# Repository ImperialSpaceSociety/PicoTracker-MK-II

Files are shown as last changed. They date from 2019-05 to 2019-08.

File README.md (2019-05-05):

# Pico Balloon Tracker Version 2.0

## Objectives
This Pico balloon tracker is the second version to be designed by Imperial College Space Society. It is intended to offer an easy to build and low cost entry for people who want to launch small Helium filled balloons with a small tracking payload. While the previous version used already built commercial modules for the radio, GPS and power supply, this version is built from basic components.
Ideally, it should be able to fly around the world on board a small balloon.

## License

Hardware is Licensed under CERN OHL v.1.2 or later https://www.ohwr.org/documents/294 No warranty is provided for this documentation implied or otherwise.

Software is licensed under MIT License.

MIT License

Copyright (c) 2018 Imperial College Space Society

Derived Software  Copyright (c) 2014  Richard Meadows <richardeoin>

Permission is hereby granted, free of charge, to any person obtaining a copy of this software and associated documentation files (the "Software"), to deal in the Software without restriction, including without limitation the rights to use, copy, modify, merge, publish, distribute, sublicense, and/or sell copies of the Software, and to permit persons to whom the Software is furnished to do so, subject to the following conditions:

The above copyright notice and this permission notice shall be included in all copies or substantial portions of the Software.

THE SOFTWARE IS PROVIDED "AS IS", WITHOUT WARRANTY OF ANY KIND, EXPRESS OR IMPLIED, INCLUDING BUT NOT LIMITED TO THE WARRANTIES OF MERCHANTABILITY, FITNESS FOR A PARTICULAR PURPOSE AND NONINFRINGEMENT. IN NO EVENT SHALL THE AUTHORS OR COPYRIGHT HOLDERS BE LIABLE FOR ANY CLAIM, DAMAGES OR OTHER LIABILITY, WHETHER IN AN ACTION OF CONTRACT, TORT OR OTHERWISE, ARISING FROM, OUT OF OR IN CONNECTION WITH THE SOFTWARE OR THE USE OR OTHER DEALINGS IN THE SOFTWARE.

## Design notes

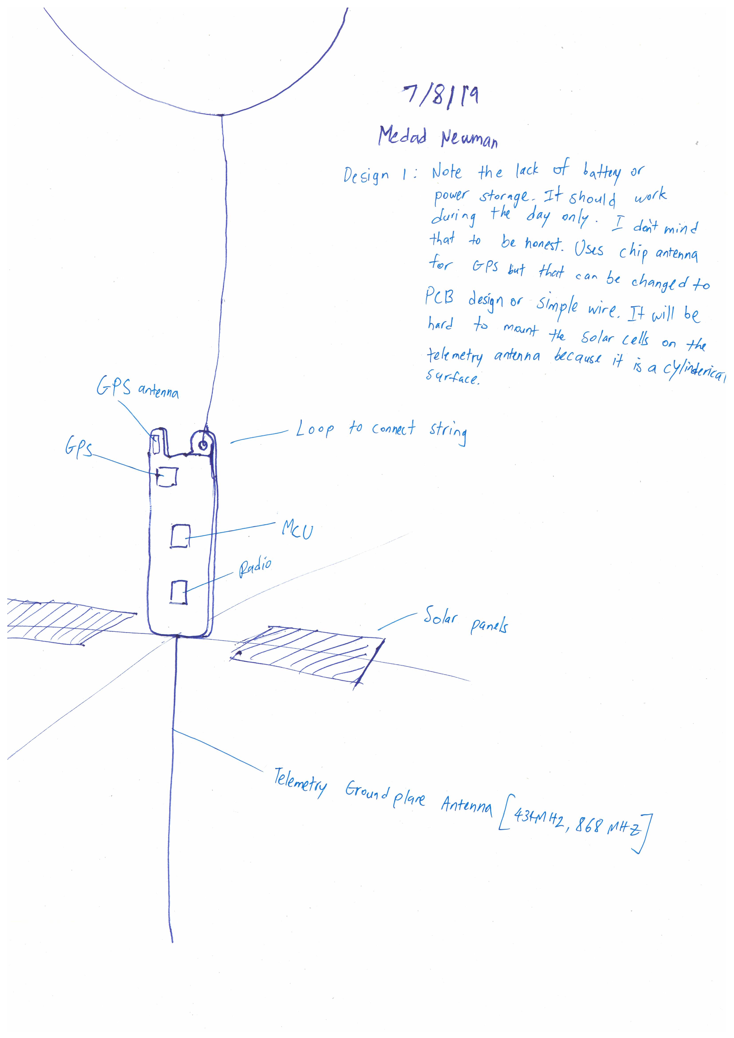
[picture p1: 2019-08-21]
prototype/hardware/Plans/Design 1.jpg

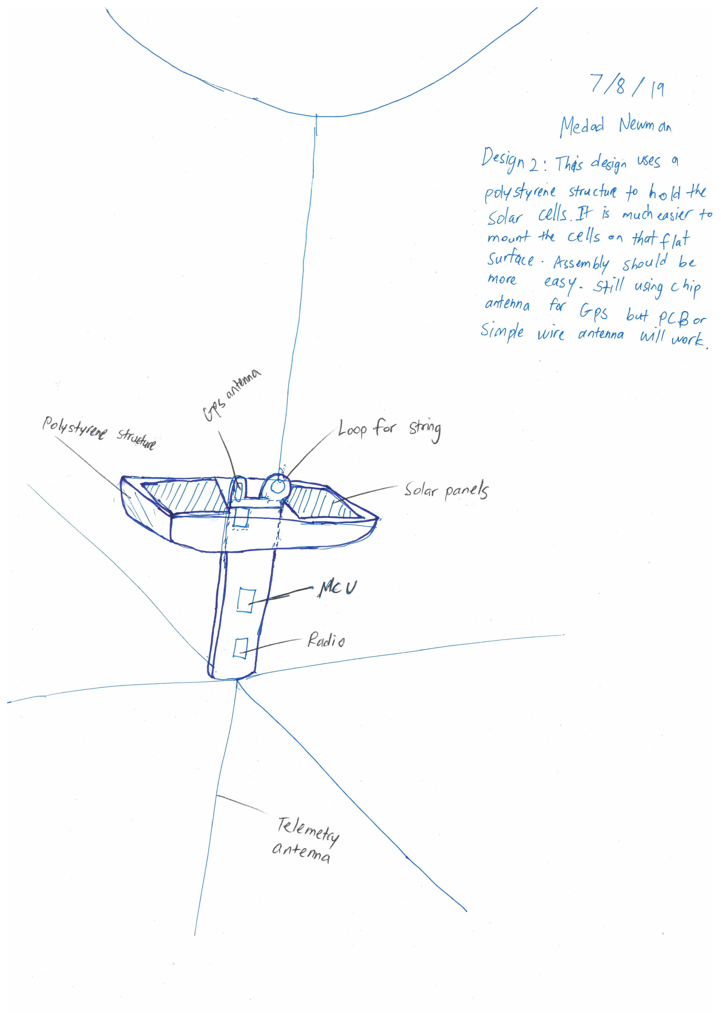
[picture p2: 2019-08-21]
prototype/hardware/Plans/Design 2.jpg

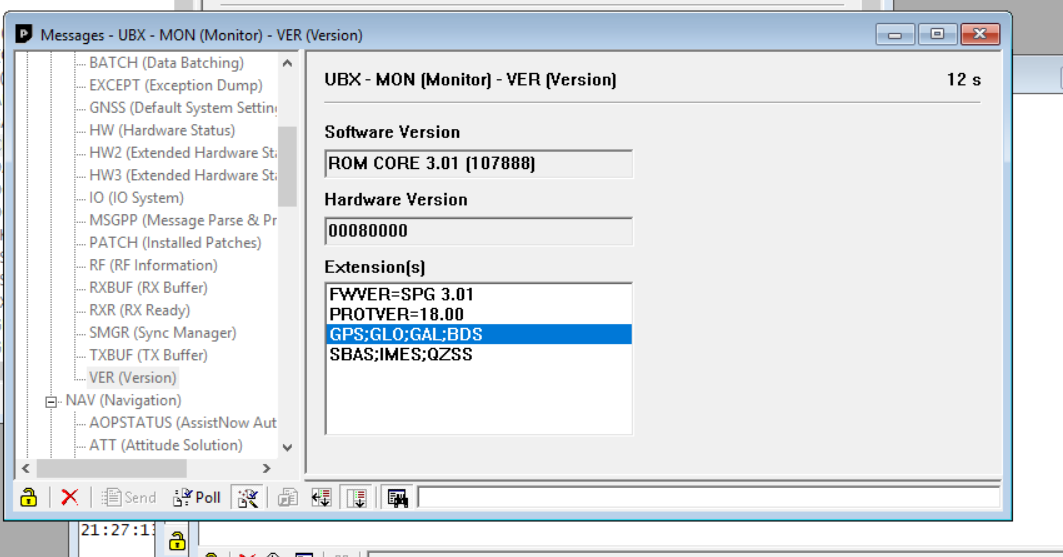
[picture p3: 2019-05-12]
prototype/hardware/GPS information/version information.PNG

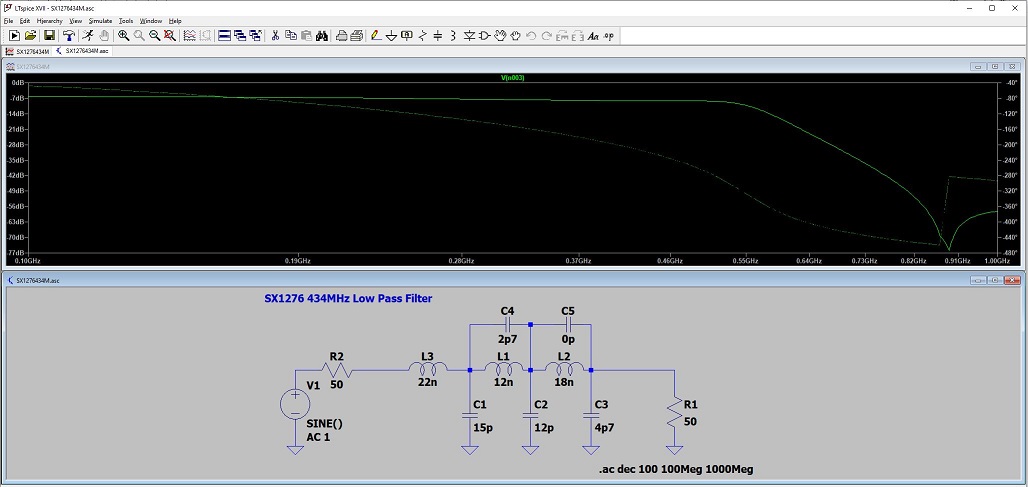
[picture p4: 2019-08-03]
Spice/SX1276434MHz.JPG

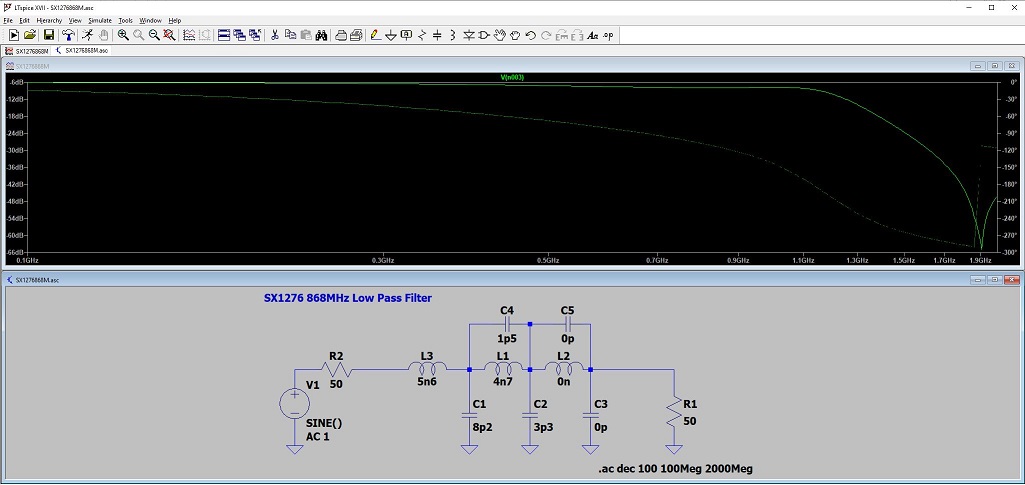
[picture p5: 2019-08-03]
Spice/SX1276868MHz.JPG

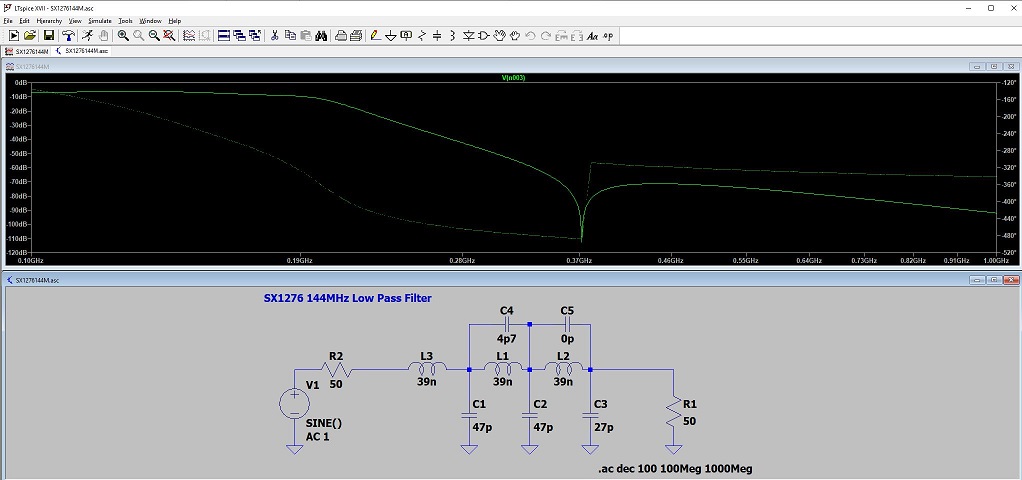
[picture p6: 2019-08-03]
Spice/SX1276144MHz.JPG

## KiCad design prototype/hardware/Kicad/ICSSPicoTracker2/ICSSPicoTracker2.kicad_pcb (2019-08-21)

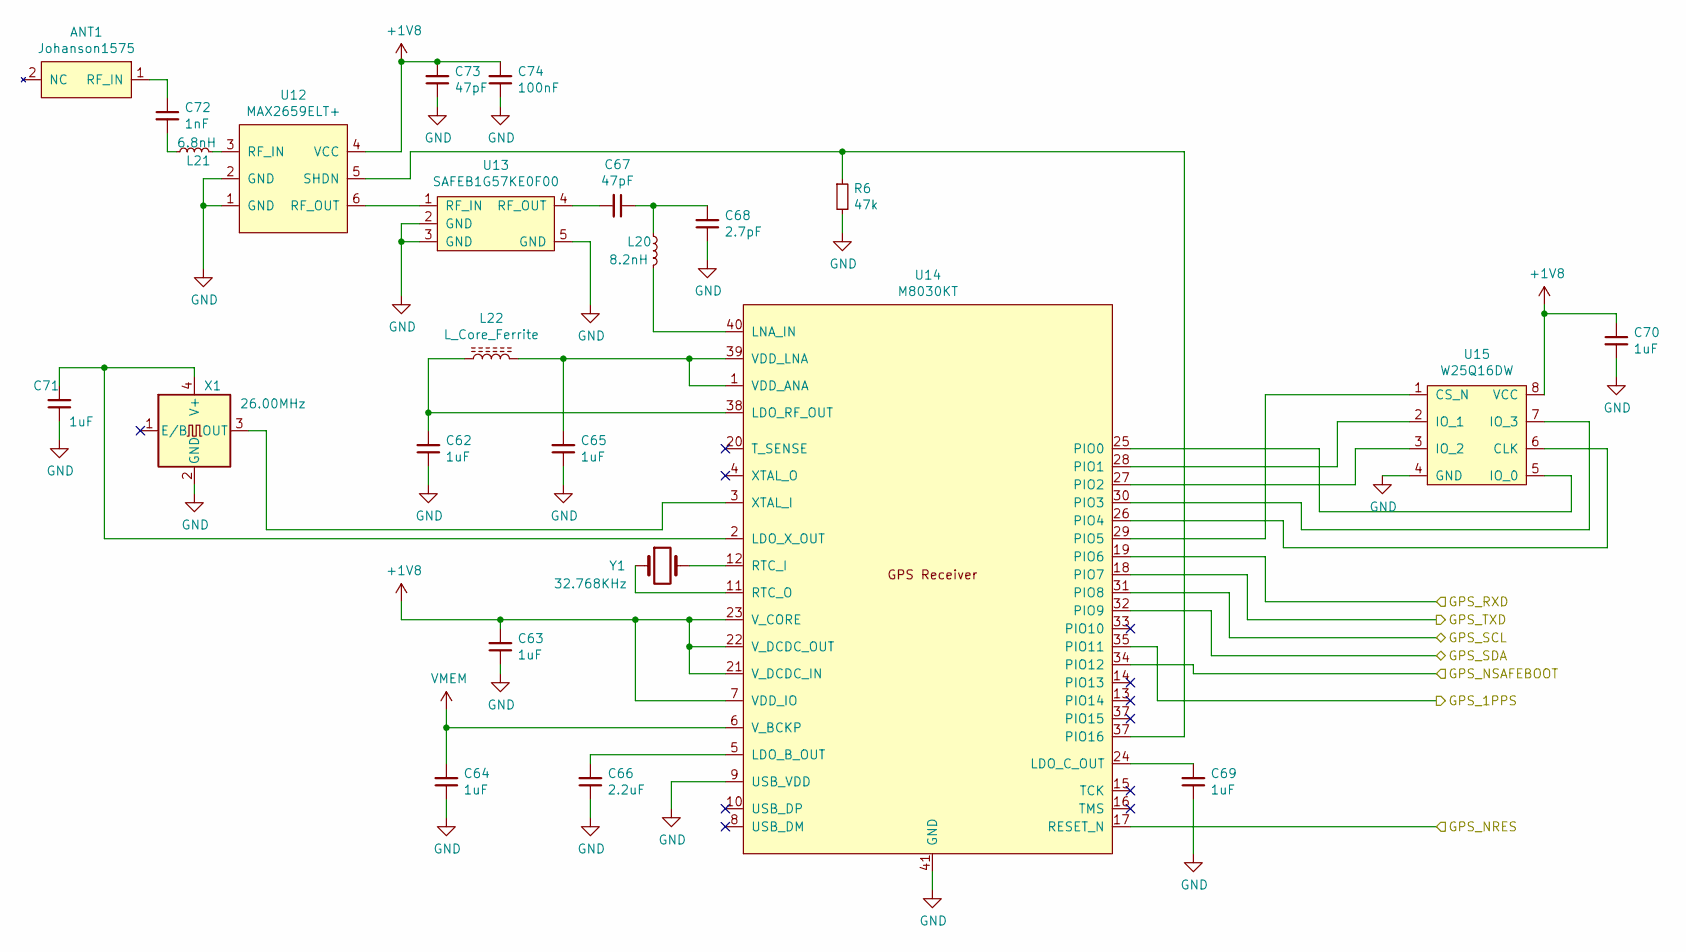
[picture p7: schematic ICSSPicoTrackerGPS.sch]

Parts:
ANT1: Johanson1575
C62, C63, C64, C65, C69, C70, C71: 1uF; C_0603_1608Metric
C66: 2.2uF; C_0603_1608Metric
C67, C73: 47pF; C_0402_1005Metric
C68: 2.7pF; C_0402_1005Metric
C72: 1nF; C_0402_1005Metric
C74: 100nF; C_0603_1608Metric
L20: 8.2nH; L_0402_1005Metric
L21: 6.8nH; L_0402_1005Metric
L22: L_Core_Ferrite; L_0603_1608Metric
R6: 47k; R_0603_1608Metric
U12: MAX2659ELT+; uDFN-6_1.0x1.5mm_P0.5mm
U13: SAFEB1G57KE0F00; Murata SAFE
U14: M8030KT; QFN-40-1EP_5x5mm_P0.4mm_EP3.6x3.6mm_ThermalVias
U15: W25Q16DW; WSON-8-1EP_6x5mm_P1.27mm_EP3.4x4.3mm
X1: 26.00MHz; Oscillator_SMD_IQD_IQXO70-4Pin_7.5x5.0mm
Y1: 32.768KHz; Crystal_SMD_2012-2Pin_2.0x1.2mm

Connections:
+1V8: C63.2, C70.1, C73.2, C74.2, U12.4 (VCC), U14.7 (VDD_IO), U14.21 (V_DCDC_IN), U14.22 (V_DCDC_OUT), U14.23 (V_CORE), U15.8 (VCC); also elsewhere on the board
/GPS/GPS_1PPS: U14.35 (PIO11); also elsewhere on the board
/GPS/GPS_NRES: U14.17 (RESET_N); also elsewhere on the board
/GPS/GPS_NSAFEBOOT: U14.34 (PIO12); also elsewhere on the board
/GPS/GPS_RXD: U14.19 (PIO6); also elsewhere on the board
/GPS/GPS_SCL: U14.31 (PIO8); also elsewhere on the board
/GPS/GPS_SDA: U14.32 (PIO9); also elsewhere on the board
/GPS/GPS_TXD: U14.18 (PIO7); also elsewhere on the board
GND: C62.1, C63.1, C64.1, C65.1, C66.1, C68.1, C69.1, C70.2, C71.1, C73.1, C74.1, R6.2, U12.1 (GND), U12.2 (GND), U13.2 (GND), U13.3 (GND), U13.5 (GND), U14.9 (USB_VDD), U14.41 (GND), U15.4 (GND), X1.2 (GND); also elsewhere on the board
unnamed: ANT1.1 (RF_IN), C72.1
unnamed: C62.2, L22.1, U14.38 (LDO_RF_OUT)
unnamed: C65.2, L22.2, U14.1 (VDD_ANA), U14.39 (VDD_LNA)
unnamed: C66.2, U14.5 (LDO_B_OUT)
unnamed: C67.1, C68.2, L20.1
unnamed: C67.2, U13.4 (RF_OUT)
unnamed: C69.2, U14.24 (LDO_C_OUT)
unnamed: C71.2, U14.2 (LDO_X_OUT), X1.4 (V+)
unnamed: C72.2, L21.2
unnamed: L20.2, U14.40 (LNA_IN)
unnamed: L21.1, U12.3 (RF_IN)
unnamed: U12.6 (RF_OUT), U13.1 (RF_IN)
unnamed: U14.3 (XTAL_I), X1.3 (OUT)
unnamed: U14.11 (RTC_O), Y1.1
unnamed: U14.12 (RTC_I), Y1.2
unnamed: U14.25 (PIO0), U15.5 (IO_0)
unnamed: U14.26 (PIO4), U15.6 (CLK)
unnamed: U14.27 (PIO2), U15.3 (IO_2)
unnamed: U14.28 (PIO1), U15.2 (IO_1)
unnamed: U14.29 (PIO5), U15.1 (CS_N)
unnamed: U14.30 (PIO3), U15.7 (IO_3)
VMEM: C64.2, U14.6 (V_BCKP); also elsewhere on the board

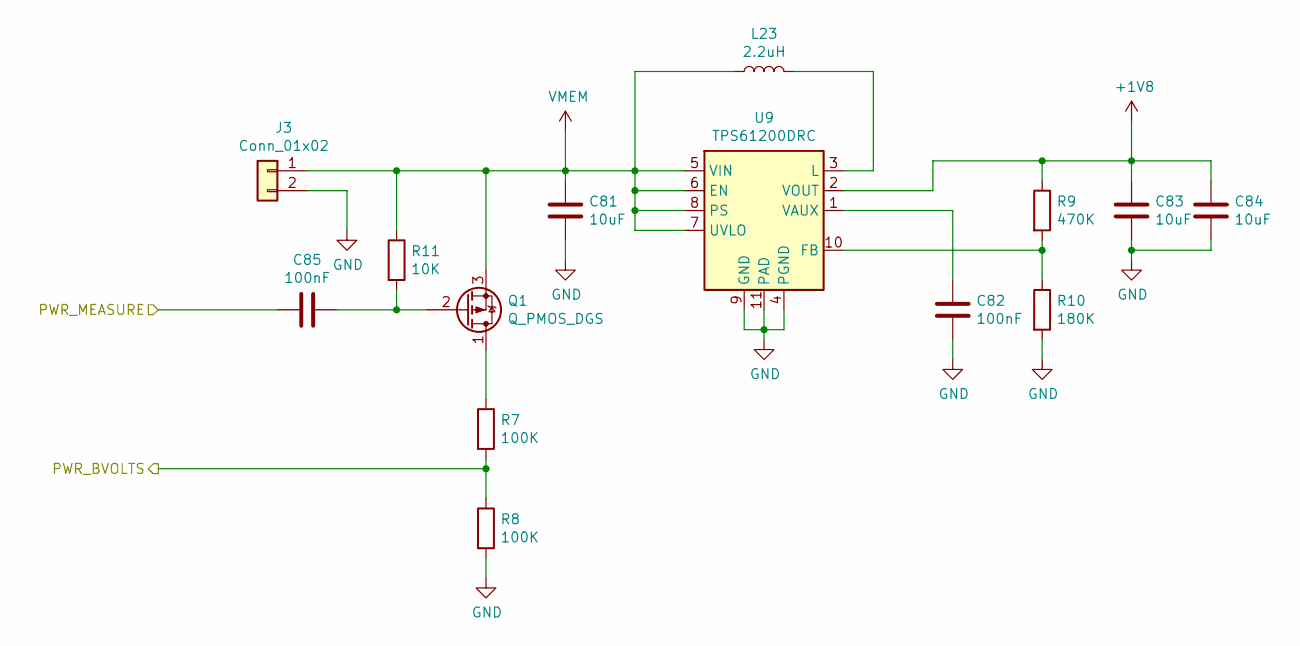
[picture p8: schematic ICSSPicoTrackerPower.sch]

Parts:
C81, C83, C84: 10uF; C_0603_1608Metric
C82, C85: 100nF; C_0603_1608Metric
J3: Conn_01x02; PinHeader_1x02_P1.00mm_Vertical
L23: 2.2uH; L_Taiyo-Yuden_NR-30xx
Q1: Q_PMOS_DGS; SOT-23
R7, R8: 100K; R_0603_1608Metric
R9: 470K; R_0603_1608Metric
R10: 180K; R_0603_1608Metric
R11: 10K; R_0603_1608Metric
U9: TPS61200DRC; Texas_S-PVSON-N10_ThermalVias

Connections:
+1V8: C83.1, C84.1, R9.1, U9.2 (VOUT); also elsewhere on the board
/MCU/MCU_PA02: R7.2, R8.1; also elsewhere on the board
/MCU/MCU_PA13: C85.1; also elsewhere on the board
GND: C81.2, C82.2, C83.2, C84.2, J3.2, R8.2, R10.2, U9.4 (PGND), U9.9 (GND), U9.11 (PAD); also elsewhere on the board
unnamed: C82.1, U9.1 (VAUX)
unnamed: C85.2, Q1.2 (G), R11.2
unnamed: L23.2, U9.3 (L)
unnamed: Q1.1 (D), R7.1
unnamed: R9.2, R10.1, U9.10 (FB)
VMEM: C81.1, J3.1, L23.1, Q1.3 (S), R11.1, U9.5 (VIN), U9.6 (EN), U9.7 (UVLO), U9.8 (PS); also elsewhere on the board

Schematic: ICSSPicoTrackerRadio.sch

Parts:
ANT2: Johanson868
ANT3: Yageo434
C8, C10, C11, C12, C14, C61, C75: 100nF; C_0603_1608Metric
C13, C19, C31, C32, C42, C43, C50, C51, C57, C58, C59: 47pF; C_0402_1005Metric
C15: 10nF; C_0402_1005Metric
C16, C17, C24: 8.2pF; C_0402_1005Metric
C18: 27pF; C_0402_1005Metric
C20: 22pF; C_0402_1005Metric
C21: 100pF; C_0402_1005Metric
C22, C26, C36, C37, C38, C40, C44, C45, C52, C53, C54, C55: NF; C_0402_1005Metric
C23: 15pF; C_0402_1005Metric
C25, C35: 56pF; C_0402_1005Metric
C27, C34: 3.3pF; C_0402_1005Metric
C28: 2.7pF; C_0402_1005Metric
C29: 1.5pF; C_0402_1005Metric
C30, C39, C60: 4.7pF; C_0402_1005Metric
C33: 12pF; C_0402_1005Metric
C41: 33pF; C_0402_1005Metric
C46, C47, C48, C49: 1nF; C_0402_1005Metric
C56: 220pF; C_0402_1005Metric
J4: Conn_01x02; PinHeader_1x02_P2.54mm_Vertical
L2, L8, L13, L16: 47nH; L_0402_1005Metric
L3: 33nH; L_0402_1005Metric
L4: 100nH; L_0402_1005Metric
L5, L14: 18nH; L_0402_1005Metric
L6: 22nH; L_0402_1005Metric
L7: 5.6nH; L_0402_1005Metric
L9, L15, L17, L18, L19: 0R; L_0402_1005Metric
L10: 10nH; L_0402_1005Metric
L11: 12nH; L_0402_1005Metric
L12: 4.7nH; L_0402_1005Metric
R2, R3: 0R; R_0603_1608Metric
R4, R5: 1K; R_0603_1608Metric
U4, U5: PE4259; SOT-363_SC-70-6_Handsoldering
U6: SX1276; QFN-28-1EP_6x6mm_P0.65mm_EP4.25x4.25mm_ThermalVias
U11: 74LVC1G04; SOT-353_SC-70-5
X2: IQXO-70; Oscillator_SMD_SeikoEpson_SG210-4Pin_2.5x2.0mm

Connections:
+1V8: C8.1, C10.1, C13.1, C14.1, C48.1, C49.1, C61.1, C75.1, U4.6 (VDD), U5.6 (VDD), U6.3 (VBAT_ANA), U6.14 (VBAT_DIG), U6.24 (VBAT_RF), U11.5 (VCC), X2.4 (V+); also elsewhere on the board
/MCU/MCU_MISO1: U6.17 (MISO); also elsewhere on the board
/MCU/MCU_MOSI1: U6.18 (MOSI); also elsewhere on the board
/MCU/MCU_NSEL1: U6.19 (NSS); also elsewhere on the board
/MCU/MCU_PA03: U6.13 (DIO5); also elsewhere on the board
/MCU/MCU_PA04: U6.12 (DIO4); also elsewhere on the board
/MCU/MCU_PA05: U6.11 (DIO3); also elsewhere on the board
/MCU/MCU_PA06: U6.10 (DIO2); also elsewhere on the board
/MCU/MCU_PA07: U6.9 (DIO1); also elsewhere on the board
/MCU/MCU_PA08: U6.8 (DIO0); also elsewhere on the board
/MCU/MCU_PA09: U6.7 (NRESET); also elsewhere on the board
/MCU/MCU_SCLK1: U6.16 (SCK); also elsewhere on the board
/Telemetry Radio/RFSW_RX: R4.2, U11.4
/Telemetry Radio/RFSW_TX: R5.2, U6.20 (RXTX/RFMOD), U11.2
GND: C8.2, C10.2, C11.2, C12.2, C13.2, C14.2, C15.2, C16.2, C17.2, C18.2, C22.2, C23.2, C24.2, C25.2, C26.2, C27.2, C33.2, C34.2, C35.2, C39.2, C40.2, C41.2, C44.2, C45.2, C46.2, C47.2, C48.2, C49.2, C52.2, C53.2, C54.2, C55.2, C56.2, C57.2, C58.2, C59.2, C61.2, C75.2, J4.2, L5.2, U4.2 (GND), U5.2 (GND), U6.15 (GND), U6.23 (GND), U6.26 (GND), U6.29 (GND), U11.3 (GND), X2.2 (GND); also elsewhere on the board
unnamed: ANT2.1 (RF_IN), C55.1, L19.2
unnamed: ANT3.1, C54.1, L18.2
unnamed: C11.1, U6.2 (VR_ANA)
unnamed: C12.1, U6.4 (VR_DIG)
unnamed: C15.1, C56.1, C57.1, C58.1, C59.1, L2.1, L3.1, L4.1, U6.25 (VR_PA)
unnamed: C16.1, C19.2, L2.2, U6.28 (RFO_LF)
unnamed: C17.1, C20.2, L3.2, U6.22 (RFO_HF)
unnamed: C18.1, C21.2, L4.2, L9.2
unnamed: C19.1, L6.1
unnamed: C20.1, L7.1
unnamed: C21.1, L8.1
unnamed: C22.1, L10.1, U6.21 (RFI_HF)
unnamed: C23.1, C28.2, L6.2, L11.1
unnamed: C24.1, C29.2, L7.2, L12.1
unnamed: C25.1, C30.2, L8.2, L13.1
unnamed: C26.1, C31.2, C60.1
unnamed: C27.1, C32.2, L10.2
unnamed: C28.1, C33.1, C36.2, L11.2, L14.1
unnamed: C29.1, C34.1, C37.2, L12.2, L15.1
unnamed: C30.1, C35.1, C38.2, L13.2, L16.1
unnamed: C31.1, R2.2
unnamed: C32.1, R3.2
unnamed: C36.1, C39.1, L14.2, U4.3 (RF2)
unnamed: C37.1, C40.1, L15.2, U5.1 (RF1)
unnamed: C38.1, C41.1, C44.1, L16.2, L17.2
unnamed: C42.1, U4.1 (RF1)
unnamed: C42.2, R2.1
unnamed: C43.1, U5.3 (RF2)
unnamed: C43.2, R3.1
unnamed: C45.1, J4.1, L17.1
unnamed: C46.1, R4.1, U4.4 (CTRL)
unnamed: C47.1, R5.1, U5.4 (CTRL)
unnamed: C50.1, C52.1, L18.1
unnamed: C50.2, U4.5 (RFC)
unnamed: C51.1, C53.1, L19.1
unnamed: C51.2, U5.5 (RFC)
unnamed: C60.2, L5.1, U6.1 (RFI_LF)
unnamed: L9.1, U6.27 (PA_BOOST)
unnamed: U6.5 (XTA), X2.3 (OUT)

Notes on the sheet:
144MHz Tx
433MHz Tx/Rx
868MHz Tx/Rx
144MHz Low Pass Filter
144MHz Antenna Match
144MHz TX Bias
144MHz TX Match
Rx/Tx Switch
868MHz TX Bias
868MHz TX Match
868MHz Low Pass Filter
868MHz Antenna Match
434MHz RX Match
434MHz Tx Bias
434MHz Tx Match
434MHz Low pass Filter
434MHz Antenna match
868Hz RX Match

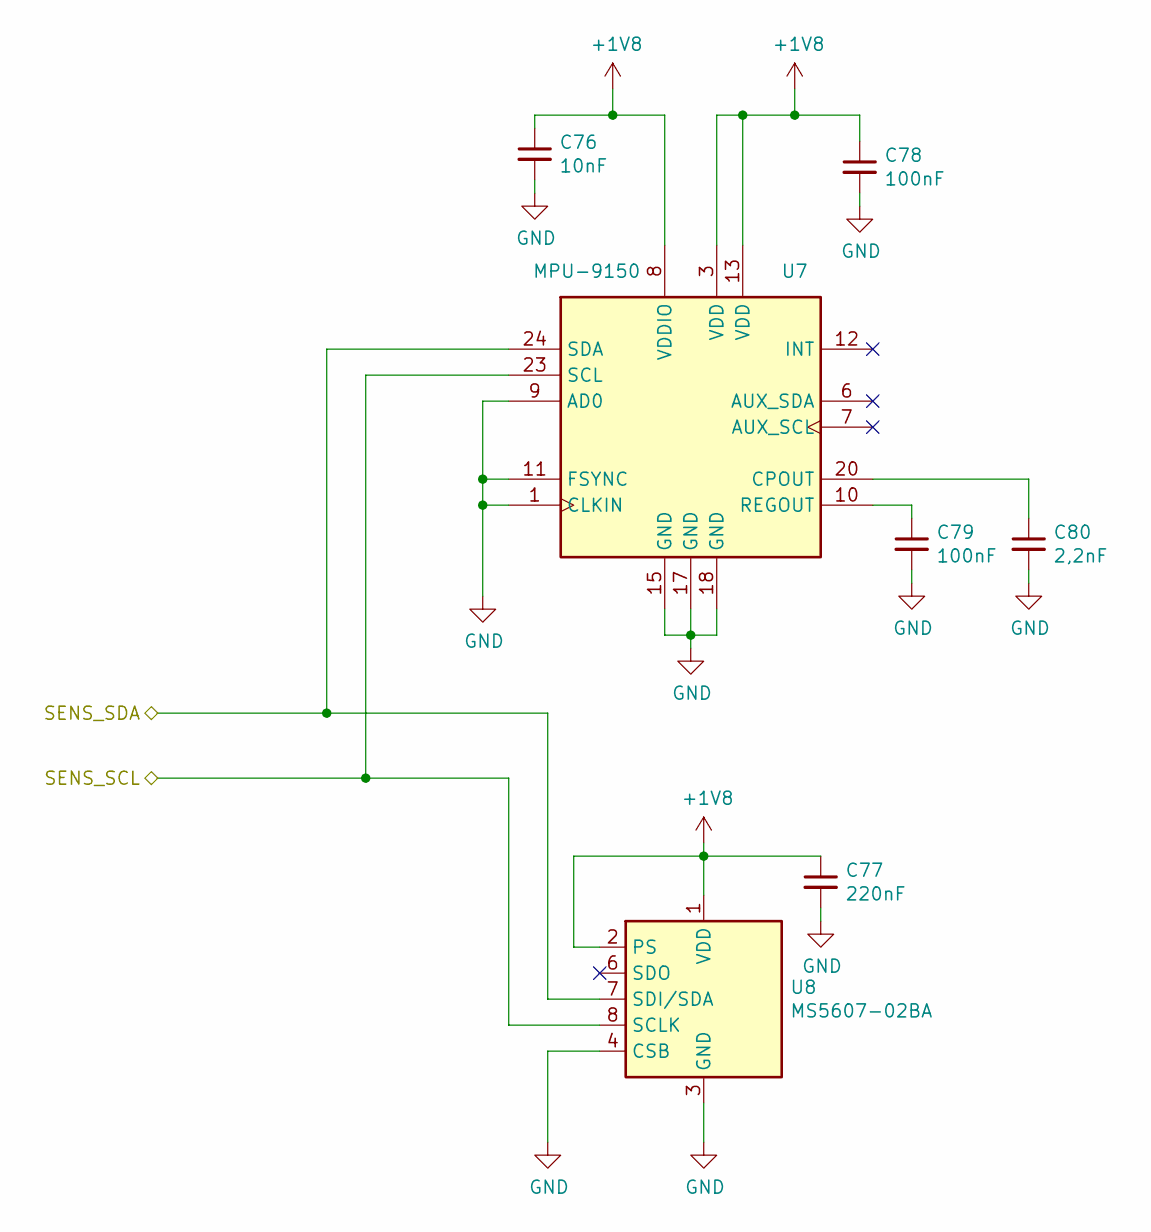
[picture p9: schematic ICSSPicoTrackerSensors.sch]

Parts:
C76: 10nF; C_0402_1005Metric
C77: 220nF; C_0402_1005Metric
C78, C79: 100nF; C_0603_1608Metric
C80: 2,2nF; C_0402_1005Metric
U7: MPU-9150; InvenSense_QFN-24_4x4mm_P0.5mm
U8: MS5607-02BA; LGA-8_3x5mm_P1.25mm

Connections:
+1V8: C76.1, C77.1, C78.1, U7.3 (VDD), U7.8 (VDDIO), U7.13 (VDD), U8.1 (VDD), U8.2 (PS); also elsewhere on the board
/GPS/GPS_SCL: U7.23 (SCL), U8.8 (SCLK); also elsewhere on the board
/GPS/GPS_SDA: U7.24 (SDA), U8.7 (SDI/SDA); also elsewhere on the board
GND: C76.2, C77.2, C78.2, C79.2, C80.2, U7.1 (CLKIN), U7.9 (AD0), U7.11 (FSYNC), U7.15 (GND), U7.17 (GND), U7.18 (GND), U8.3 (GND), U8.4 (CSB), U8.5 (CSB); also elsewhere on the board
unnamed: C79.1, U7.10 (REGOUT)
unnamed: C80.1, U7.20 (CPOUT)

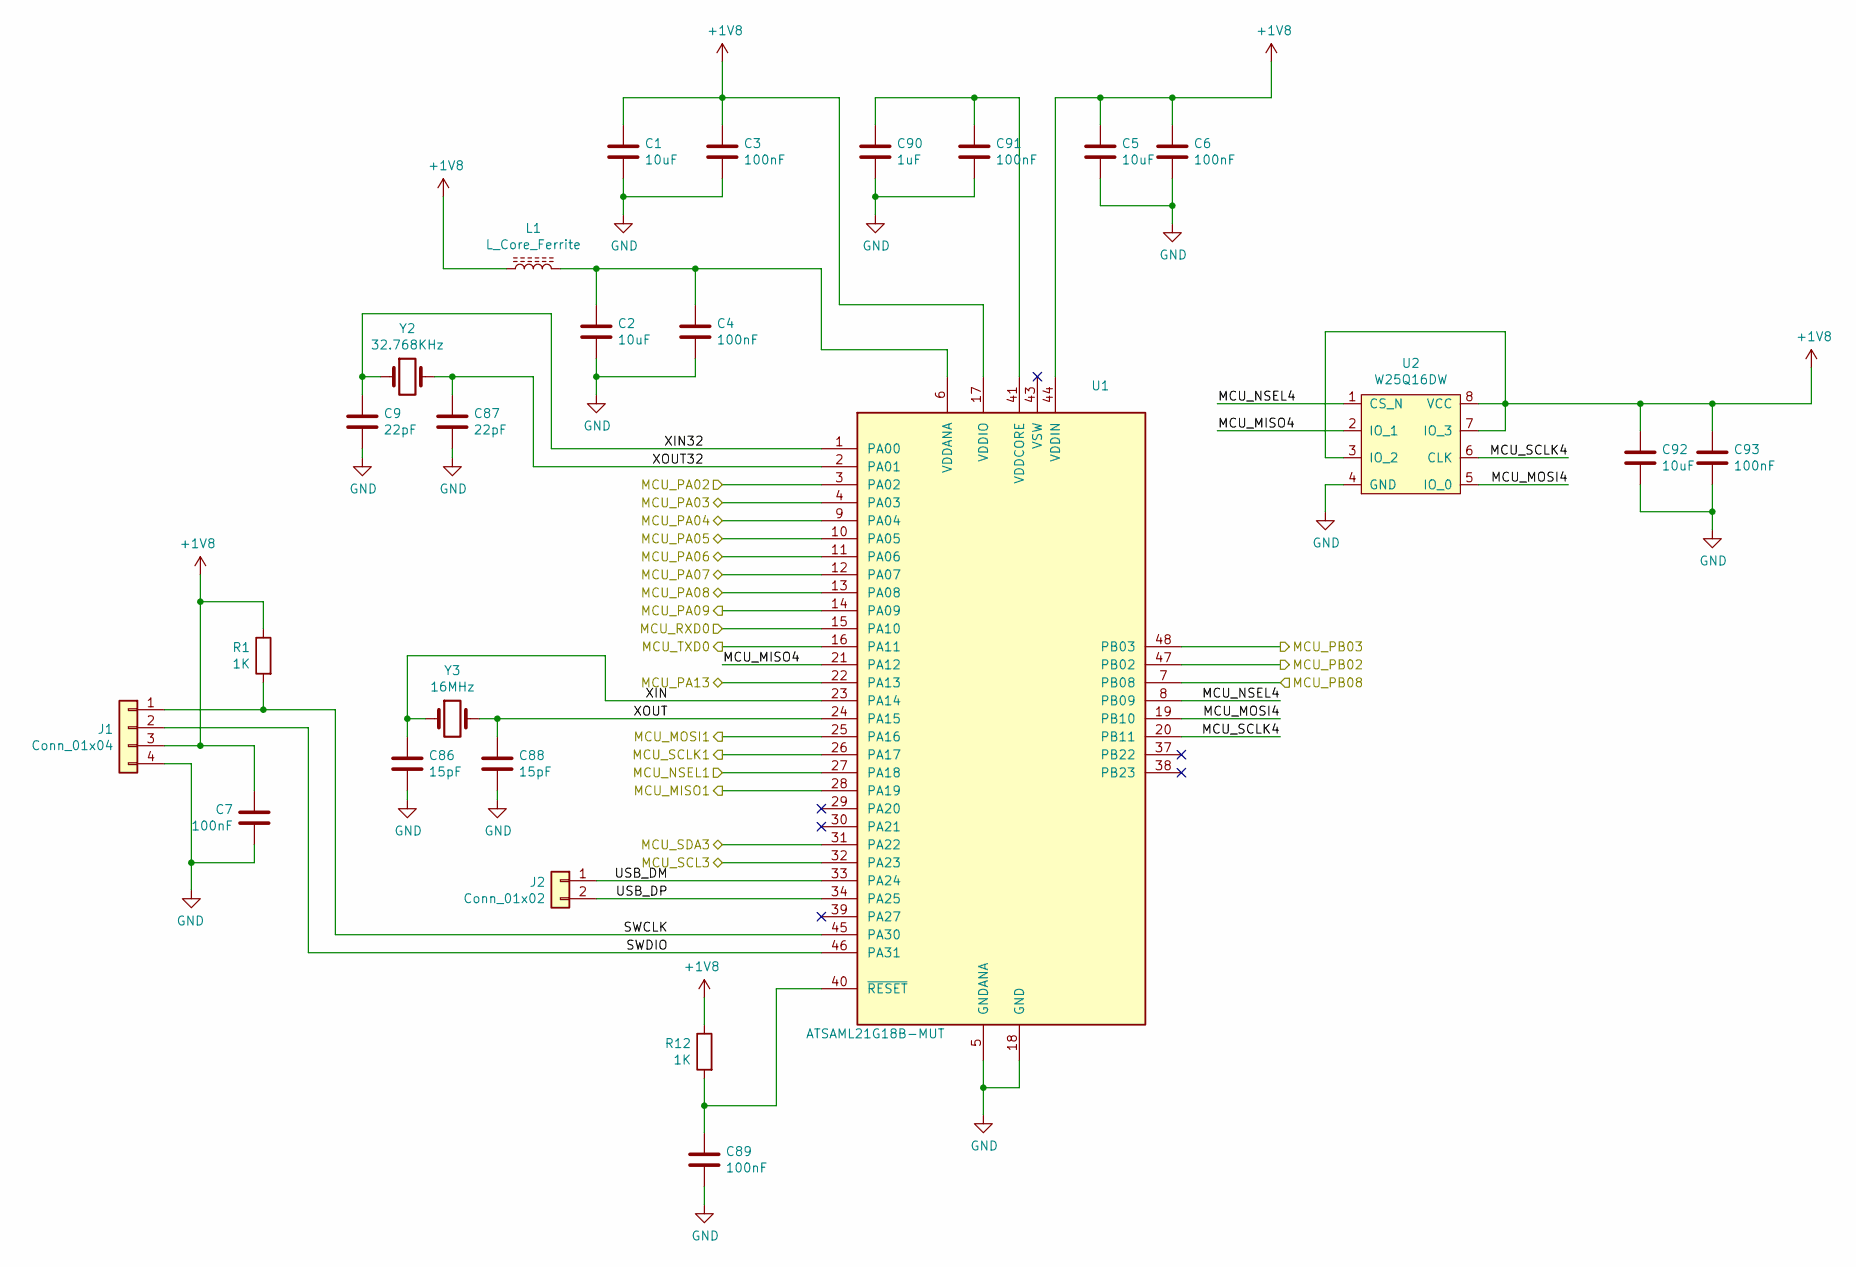
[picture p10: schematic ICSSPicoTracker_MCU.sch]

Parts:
C1, C2, C5, C92: 10uF; C_0603_1608Metric
C3, C4, C6, C7, C89, C91, C93: 100nF; C_0603_1608Metric
C9, C87: 22pF; C_0402_1005Metric
C86, C88: 15pF; C_0402_1005Metric
C90: 1uF; C_0603_1608Metric
J1: Conn_01x04; PinHeader_1x04_P1.00mm_Vertical
J2: Conn_01x02; PinHeader_1x02_P1.00mm_Vertical
L1: L_Core_Ferrite; L_0603_1608Metric
R1, R12: 1K; R_0603_1608Metric
U1: ATSAML21G18B-MUT; QFN-48-1EP_7x7mm_P0.5mm_EP5.15x5.15mm
U2: W25Q16DW; WSON-8-1EP_6x5mm_P1.27mm_EP3.4x4.3mm
Y2: 32.768KHz; Crystal_SMD_2012-2Pin_2.0x1.2mm
Y3: 16MHz; Crystal_SMD_2520-4Pin_2.5x2.0mm

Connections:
+1V8: C1.1, C3.1, C5.1, C6.1, C7.1, C92.1, C93.1, J1.3, L1.1, R1.1, R12.1, U1.17 (VDDIO), U1.36 (VDDIO), U1.44 (VDDIN), U2.3 (IO_2), U2.7 (IO_3), U2.8 (VCC); also elsewhere on the board
/GPS/GPS_1PPS: U1.7 (PB08); also elsewhere on the board
/GPS/GPS_NRES: U1.47 (PB02); also elsewhere on the board
/GPS/GPS_NSAFEBOOT: U1.48 (PB03); also elsewhere on the board
/GPS/GPS_RXD: U1.16 (PA11); also elsewhere on the board
/GPS/GPS_SCL: U1.32 (PA23); also elsewhere on the board
/GPS/GPS_SDA: U1.31 (PA22); also elsewhere on the board
/GPS/GPS_TXD: U1.15 (PA10); also elsewhere on the board
/MCU/MCU_MISO1: U1.28 (PA19); also elsewhere on the board
/MCU/MCU_MISO4: U1.21 (PA12), U2.2 (IO_1)
/MCU/MCU_MOSI1: U1.25 (PA16); also elsewhere on the board
/MCU/MCU_MOSI4: U1.19 (PB10), U2.5 (IO_0)
/MCU/MCU_NSEL1: U1.27 (PA18); also elsewhere on the board
/MCU/MCU_NSEL4: U1.8 (PB09), U2.1 (CS_N)
/MCU/MCU_PA02: U1.3 (PA02); also elsewhere on the board
/MCU/MCU_PA03: U1.4 (PA03); also elsewhere on the board
/MCU/MCU_PA04: U1.9 (PA04); also elsewhere on the board
/MCU/MCU_PA05: U1.10 (PA05); also elsewhere on the board
/MCU/MCU_PA06: U1.11 (PA06); also elsewhere on the board
/MCU/MCU_PA07: U1.12 (PA07); also elsewhere on the board
/MCU/MCU_PA08: U1.13 (PA08); also elsewhere on the board
/MCU/MCU_PA09: U1.14 (PA09); also elsewhere on the board
/MCU/MCU_PA13: U1.22 (PA13); also elsewhere on the board
/MCU/MCU_SCLK1: U1.26 (PA17); also elsewhere on the board
/MCU/MCU_SCLK4: U1.20 (PB11), U2.6 (CLK)
/MCU/SWCLK: J1.1, R1.2, U1.45 (PA30)
/MCU/SWDIO: J1.2, U1.46 (PA31)
/MCU/USB_DM: J2.1, U1.33 (PA24)
/MCU/USB_DP: J2.2, U1.34 (PA25)
/MCU/XIN: C86.1, U1.23 (PA14), Y3.1
/MCU/XIN32: C9.1, U1.1 (PA00), Y2.1
/MCU/XOUT: C88.1, U1.24 (PA15), Y3.2
/MCU/XOUT32: C87.1, U1.2 (PA01), Y2.2
GND: C1.2, C2.2, C3.2, C4.2, C5.2, C6.2, C7.2, C9.2, C86.2, C87.2, C88.2, C89.2, C90.2, C91.2, C92.2, C93.2, J1.4, U1.5 (GNDANA), U1.18 (GND), U1.35 (GND), U1.42 (GND), U2.4 (GND); also elsewhere on the board
unnamed: C2.1, C4.1, L1.2, U1.6 (VDDANA)
unnamed: C89.1, R12.2, U1.40 (~RESET)
unnamed: C90.1, C91.1, U1.41 (VDDCORE)

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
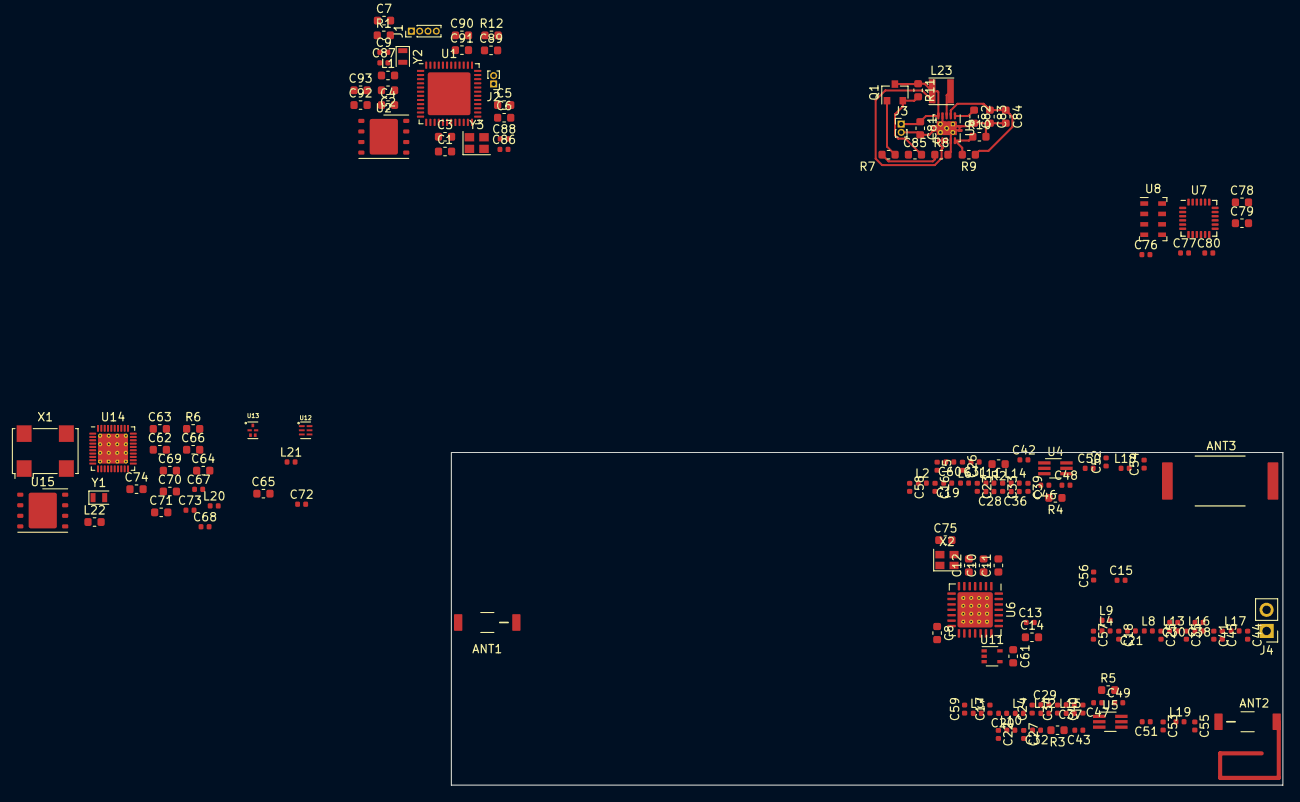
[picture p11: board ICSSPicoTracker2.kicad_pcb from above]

Board: 4 copper layers, 100.0 x 40.0 mm, 154 parts (0 on the bottom side), 108 nets.

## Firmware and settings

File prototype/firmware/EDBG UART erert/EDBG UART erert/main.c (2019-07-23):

/**
* \file
*
* \brief Application implement
*
* Copyright (c) 2015-2018 Microchip Technology Inc. and its subsidiaries.
*
* \asf_license_start
*
* \page License
*
* Subject to your compliance with these terms, you may use Microchip
* software and any derivatives exclusively with Microchip products.
* It is your responsibility to comply with third party license terms applicable
* to your use of third party software (including open source software) that
* may accompany Microchip software.
*
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
* \asf_license_stop
*
*/
/*
* Support and FAQ: visit <a href="https://www.microchip.com/support/">Microchip Support</a>
*/

#include "atmel_start.h"
#include "atmel_start_pins.h"
#include <string.h>
#include "main.h"
#include "fix.h"
#include "gps.h"
#include "BME280.h"
#include "lora.h"


/*
* the TX data buffer
* contains ASCII data, which is either transmitted as CW over RTTY
*/
uint16_t tx_buf_rdy = 0;			/* the read-flag (main -> main) */
uint16_t tx_buf_length = 0;			/* how many chars to send */
char tx_buf[TX_BUF_MAX_LENGTH] = {SYNC_PREFIX "$$" PAYLOAD_NAME ","};	/* the telemetry buffer initialised with $$ */
/* Retry counters and Operational Status*/
uint8_t  ubx_cfg_fail = 0;
uint8_t  ubx_retry_count;
uint8_t  ubx_poll_fail = 0;
extern uint16_t tlm_sent_id_length;
extern uint16_t tlm_alt_length;



/* for the temperature, humidity, pressure sensor */
int i;
uint16_t T, P, H; // calibrated values
float fP, fH;

/* The pip tone */ 
uint8_t pip[1] = {0}; // Try to use the center frequency instead of the mark or space.


/*

* telemetry format:
* - callsign
* - sentence id
* - time
* - latitude
* - longitude
* - altitude
* - available satellites
* - voltage of the AAA cell(after boosting)
* - op status
* - temperature of radio

*/

/* current (latest) GPS fix and measurements */
struct gps_fix current_fix;

void send_pips(int n){
    int i;
    for(i = 0; i < n; i++){
		SendLoRaRTTY(pip, 1);
		delay_ms(500);
	}
}
	

void get_fix(void) {
    ubx_poll_fail = 0;
	
	/* 
	 * The tracker outputs Pips while waiting for a good GPS fix.
     */
	
	current_fix.num_svs = 0; 
	current_fix.type = 3;

	while (1) {
		
		/* check if we have a fix*/		
		gps_get_fix(&current_fix);
		
		// TODO: use the GPS status bit to check if the fix is valid
		//current_fix.type = 3; // TEMP

		/* check if we have a 3D fix */
		if (current_fix.type == 3){
			break;
		};
				
		/* send pip */
		send_pips(4);

	}   

}


void get_measurements(void){
	bme280ReadValues(&T, &P, &H);
	T -= 150; // for some reason, the sensor reports temperatures too high
	//fP = (float) P / 2.56;
	//fH = (float) H / 10.24;
	
	current_fix.temp_BME280 = T;
    current_fix.op_status = ((ubx_cfg_fail & 0x03) << 2) | ((ubx_poll_fail & 0x03)); //send operational status
}

void transmit_sequence(){
	/* now wake up the GPS */
	gps_wake_up();
		
	/* now put the gps in full power mode */
	while(!(gps_power_save(0)));
	
	/* get the gps fix */
	get_fix();
	
	/* put the gps back to power save mode(sleep) */
	while(!(gps_power_save(1)));
	
	/* get voltage  and temperature*/
	get_measurements(); 
	
	/* create the telemetry string */
	prepare_tx_buffer();
		
	/* send out the data */
	tx_buf_length  = TX_BUF_FRAME_END;
	SendLoRaRTTY(tx_buf, tx_buf_length);	
}

int main(void)
{
	
	/* Initializes MCU, drivers and middleware */
	atmel_start_init();
	usart_sync_enable(&USART_0);	
	
	lora_init();

	/* Initialise BME280 */
	while(BME280Init(0x76));
	delay_ms(100); // wait for data to settle for first read

	/* Initialise GPS */   
	gps_wake_up();
	
	// TODO: add to the op byte
    //while(!(gps_cfg_reset()));
	while(!(gps_disable_nmea_output()));
	while(!(gps_set_power_save()));
	while(!(gps_set_gps_only()));
	while(!(gps_set_airborne_model()));
          
 	/* Get a single GPS fix from a cold start. Does not carry on until it has a
	 * solid fix
	*/
	get_fix();
	get_measurements();

	while(!(gps_power_save(1)));
	while(!(gps_save_settings()));
					
	SendLoRaRTTY(tx_buf, tx_buf_length);
		
	/* MAIN */
	while (1) {
		
		// shift: 365Hz, 7 bit ASCII, no parity, 2 stop bits, 434.000Mhz
		
		CheckFSKBuffers();
		delay_us(100);
		
		if(FSKPacketSent())
		{
			transmit_sequence();
			/* sleep */
			// Make it sleep here
			// TODO clean this area up.
			
		}else{
			
		}

	} /* MAIN */
}

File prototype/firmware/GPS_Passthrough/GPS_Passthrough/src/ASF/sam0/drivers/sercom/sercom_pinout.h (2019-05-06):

/**
 * \file
 *
 * \brief SAM SERCOM Module Pinout Definitions
 *
 * Copyright (c) 2012-2018 Microchip Technology Inc. and its subsidiaries.
 *
 * \asf_license_start
 *
 * \page License
 *
 * Subject to your compliance with these terms, you may use Microchip
 * software and any derivatives exclusively with Microchip products.
 * It is your responsibility to comply with third party license terms applicable
 * to your use of third party software (including open source software) that
 * may accompany Microchip software.
 *
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
 * \asf_license_stop
 *
 */
/*
 * Support and FAQ: visit <a href="https://www.microchip.com/support/">Microchip Support</a>
 */
#ifndef SERCOM_PINOUT_H_INCLUDED
#define SERCOM_PINOUT_H_INCLUDED

#include <compiler.h>

#if SAMR21E
	/* SERCOM0 */
	#define SERCOM0_PAD0_DEFAULT      PINMUX_PA08C_SERCOM0_PAD0
	#define SERCOM0_PAD1_DEFAULT      PINMUX_PA09C_SERCOM0_PAD1
	#define SERCOM0_PAD2_DEFAULT      PINMUX_PA06D_SERCOM0_PAD2
	#define SERCOM0_PAD3_DEFAULT      PINMUX_PA07D_SERCOM0_PAD3

	/* SERCOM1 */
	#define SERCOM1_PAD0_DEFAULT      PINMUX_PA16C_SERCOM1_PAD0
	#define SERCOM1_PAD1_DEFAULT      PINMUX_PA17C_SERCOM1_PAD1
	#define SERCOM1_PAD2_DEFAULT      PINMUX_PA18C_SERCOM1_PAD2
	#define SERCOM1_PAD3_DEFAULT      PINMUX_PA19C_SERCOM1_PAD3

	/* SERCOM2 */
	#define SERCOM2_PAD0_DEFAULT      PINMUX_PA08D_SERCOM2_PAD0
	#define SERCOM2_PAD1_DEFAULT      PINMUX_PA09D_SERCOM2_PAD1
	#define SERCOM2_PAD2_DEFAULT      PINMUX_PA14C_SERCOM2_PAD2
	#define SERCOM2_PAD3_DEFAULT      PINMUX_PA15C_SERCOM2_PAD3

	/* SERCOM3 */
# if SAM_PART_IS_DEFINED(SAMR21E19A)
	#define SERCOM3_PAD0_DEFAULT      PINMUX_PA16D_SERCOM3_PAD0
	#define SERCOM3_PAD1_DEFAULT      PINMUX_PA17D_SERCOM3_PAD1
# else
	#define SERCOM3_PAD0_DEFAULT      PINMUX_PA27F_SERCOM3_PAD0
	#define SERCOM3_PAD1_DEFAULT      PINMUX_PA28F_SERCOM3_PAD1
#endif
	#define SERCOM3_PAD2_DEFAULT      PINMUX_PA24C_SERCOM3_PAD2
	#define SERCOM3_PAD3_DEFAULT      PINMUX_PA25C_SERCOM3_PAD3

	/* SERCOM4 */
# if SAM_PART_IS_DEFINED(SAMR21E19A)
	#define SERCOM4_PAD0_DEFAULT      PINMUX_PB08D_SERCOM4_PAD0
	#define SERCOM4_PAD1_DEFAULT      PINMUX_PB09D_SERCOM4_PAD1
	#define SERCOM4_PAD2_DEFAULT      PINMUX_PA14D_SERCOM4_PAD2
	#define SERCOM4_PAD3_DEFAULT      PINMUX_PA15D_SERCOM4_PAD3
# else
	#define SERCOM4_PAD0_DEFAULT      PINMUX_PC19F_SERCOM4_PAD0
	#define SERCOM4_PAD1_DEFAULT      PINMUX_PB31F_SERCOM4_PAD1
	#define SERCOM4_PAD2_DEFAULT      PINMUX_PB30F_SERCOM4_PAD2
	#define SERCOM4_PAD3_DEFAULT      PINMUX_PC18F_SERCOM4_PAD3
# endif

	/* SERCOM5 */
	#define SERCOM5_PAD0_DEFAULT      PINMUX_PB30D_SERCOM5_PAD0
	#define SERCOM5_PAD1_DEFAULT      PINMUX_PB31D_SERCOM5_PAD1
	#define SERCOM5_PAD2_DEFAULT      PINMUX_PA24D_SERCOM5_PAD2
	#define SERCOM5_PAD3_DEFAULT      PINMUX_PA25D_SERCOM5_PAD3

#elif SAMR21G
	/* SERCOM0 */
	#define SERCOM0_PAD0_DEFAULT      PINMUX_PA04D_SERCOM0_PAD0
	#define SERCOM0_PAD1_DEFAULT      PINMUX_PA05D_SERCOM0_PAD1
	#define SERCOM0_PAD2_DEFAULT      PINMUX_PA06D_SERCOM0_PAD2
	#define SERCOM0_PAD3_DEFAULT      PINMUX_PA07D_SERCOM0_PAD3

	/* SERCOM1 */
	#define SERCOM1_PAD0_DEFAULT      PINMUX_PA00D_SERCOM1_PAD0
	#define SERCOM1_PAD1_DEFAULT      PINMUX_PA01D_SERCOM1_PAD1
	#define SERCOM1_PAD2_DEFAULT      PINMUX_PA30D_SERCOM1_PAD2
	#define SERCOM1_PAD3_DEFAULT      PINMUX_PA31D_SERCOM1_PAD3

	/* SERCOM2 */
	#define SERCOM2_PAD0_DEFAULT      PINMUX_PA12C_SERCOM2_PAD0
	#define SERCOM2_PAD1_DEFAULT      PINMUX_PA13C_SERCOM2_PAD1
	#define SERCOM2_PAD2_DEFAULT      PINMUX_PA14C_SERCOM2_PAD2
	#define SERCOM2_PAD3_DEFAULT      PINMUX_PA15C_SERCOM2_PAD3

	/* SERCOM3 */
	#define SERCOM3_PAD0_DEFAULT      PINMUX_PA16D_SERCOM3_PAD0
	#define SERCOM3_PAD1_DEFAULT      PINMUX_PA17D_SERCOM3_PAD1
	#define SERCOM3_PAD2_DEFAULT      PINMUX_PA18D_SERCOM3_PAD2
	#define SERCOM3_PAD3_DEFAULT      PINMUX_PA19D_SERCOM3_PAD3

	/* SERCOM4 */
	#define SERCOM4_PAD0_DEFAULT      PINMUX_PC19F_SERCOM4_PAD0
	#define SERCOM4_PAD1_DEFAULT      PINMUX_PB31F_SERCOM4_PAD1
	#define SERCOM4_PAD2_DEFAULT      PINMUX_PB30F_SERCOM4_PAD2
	#define SERCOM4_PAD3_DEFAULT      PINMUX_PC18F_SERCOM4_PAD3

	/* SERCOM5 */
	#define SERCOM5_PAD0_DEFAULT      PINMUX_PA22D_SERCOM5_PAD0
	#define SERCOM5_PAD1_DEFAULT      PINMUX_PA23D_SERCOM5_PAD1
	#define SERCOM5_PAD2_DEFAULT      PINMUX_PA24D_SERCOM5_PAD2
	#define SERCOM5_PAD3_DEFAULT      PINMUX_PA25D_SERCOM5_PAD3

#elif (SAMD09)
	/* SERCOM0 */
	#define SERCOM0_PAD0_DEFAULT      PINMUX_PA04D_SERCOM0_PAD0
	#define SERCOM0_PAD1_DEFAULT      PINMUX_PA05D_SERCOM0_PAD1
	#define SERCOM0_PAD2_DEFAULT      PINMUX_PA08D_SERCOM0_PAD2
	#define SERCOM0_PAD3_DEFAULT      PINMUX_PA09D_SERCOM0_PAD3

	/* SERCOM1 */
	#define SERCOM1_PAD0_DEFAULT      PINMUX_PA30C_SERCOM1_PAD0
	#define SERCOM1_PAD1_DEFAULT      PINMUX_PA31C_SERCOM1_PAD1
	#define SERCOM1_PAD2_DEFAULT      PINMUX_PA24C_SERCOM1_PAD2
	#define SERCOM1_PAD3_DEFAULT      PINMUX_PA25C_SERCOM1_PAD3
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

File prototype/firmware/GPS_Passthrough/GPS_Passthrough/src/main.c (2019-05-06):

/**
 * GPS_Passthrough
 *
 * Test Routine for UBlox GPS Test for pass through to uCenter
 * GPS is on SERCOM1 EXT 3 port
 * PC connection is on SERCOM3 EDBG USB CDC port
 *
 */

/* This seems a bit odd. Is this not the latest ASF version ? */

/* Modified the usart.c file so it does not wait for transmit complete ! */

/*
 * Include header files for all drivers that have been imported from
 * Atmel Software Framework (ASF).
 */
/*
 * Support and FAQ: visit <a href="https://www.microchip.com/support/">Microchip Support</a>
 */
#include <asf.h>

struct usart_module edbg_uart;
struct usart_module gps_uart;


void configure_edbg_usart(void)
{
	struct usart_config config_usart;
	usart_get_config_defaults(&config_usart);
	config_usart.baudrate    = 9600;
	config_usart.mux_setting = EDBG_CDC_SERCOM_MUX_SETTING;
	config_usart.pinmux_pad0 = EDBG_CDC_SERCOM_PINMUX_PAD0;
	config_usart.pinmux_pad1 = EDBG_CDC_SERCOM_PINMUX_PAD1;
	config_usart.pinmux_pad2 = EDBG_CDC_SERCOM_PINMUX_PAD2;
	config_usart.pinmux_pad3 = EDBG_CDC_SERCOM_PINMUX_PAD3;
	while (usart_init(&edbg_uart,
	EDBG_CDC_MODULE, &config_usart) != STATUS_OK) {
	}
	usart_enable(&edbg_uart);
}
void configure_gps_usart(void)
{
	struct usart_config config_usart;
	usart_get_config_defaults(&config_usart);
	config_usart.baudrate    = 9600;
	config_usart.mux_setting = EXT3_UART_SERCOM_MUX_SETTING;
	config_usart.pinmux_pad0 = EXT3_UART_SERCOM_PINMUX_PAD0;
	config_usart.pinmux_pad1 = EXT3_UART_SERCOM_PINMUX_PAD1;
	config_usart.pinmux_pad2 = EXT3_UART_SERCOM_PINMUX_PAD2;
	config_usart.pinmux_pad3 = EXT3_UART_SERCOM_PINMUX_PAD3;
	while (usart_init(&gps_uart,
	EXT3_UART_MODULE, &config_usart) != STATUS_OK) {
	}
	usart_enable(&gps_uart);
}


int main (void)
{
	uint16_t temp;
	
	system_init();
	
	configure_edbg_usart();
	configure_gps_usart();
	
	
	while(1){
		
		if (usart_read_wait(&gps_uart, &temp) == STATUS_OK) {
			while (usart_write_wait(&edbg_uart, temp) != STATUS_OK) {
			}
		}
		
		if (usart_read_wait(&edbg_uart, &temp) == STATUS_OK) {
			while (usart_write_wait(&gps_uart, temp) != STATUS_OK) {
			}
		}
		
		
	}
}
	

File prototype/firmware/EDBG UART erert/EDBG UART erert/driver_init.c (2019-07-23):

/*
 * Code generated from Atmel Start.
 *
 * This file will be overwritten when reconfiguring your Atmel Start project.
 * Please copy examples or other code you want to keep to a separate file
 * to avoid losing it when reconfiguring.
 */

#include "driver_init.h"
#include <peripheral_clk_config.h>
#include <utils.h>
#include <hal_init.h>

struct spi_m_sync_descriptor SPI_0;

struct usart_sync_descriptor USART_0;

struct i2c_m_sync_desc I2C_0;

struct usart_sync_descriptor EDBG_COM_1;

void USART_0_PORT_init(void)
{

	gpio_set_pin_function(PA18, PINMUX_PA18C_SERCOM1_PAD2);

	gpio_set_pin_function(PA19, PINMUX_PA19C_SERCOM1_PAD3);
}

void USART_0_CLOCK_init(void)
{
	hri_gclk_write_PCHCTRL_reg(GCLK, SERCOM1_GCLK_ID_CORE, CONF_GCLK_SERCOM1_CORE_SRC | (1 << GCLK_PCHCTRL_CHEN_Pos));
	hri_gclk_write_PCHCTRL_reg(GCLK, SERCOM1_GCLK_ID_SLOW, CONF_GCLK_SERCOM1_SLOW_SRC | (1 << GCLK_PCHCTRL_CHEN_Pos));

	hri_mclk_set_APBCMASK_SERCOM1_bit(MCLK);
}

void USART_0_init(void)
{
	USART_0_CLOCK_init();
	usart_sync_init(&USART_0, SERCOM1, (void *)NULL);
	USART_0_PORT_init();
}

void I2C_0_PORT_init(void)
{

	gpio_set_pin_pull_mode(PA08,
	                       // <y> Pull configuration
	                       // <id> pad_pull_config
	                       // <GPIO_PULL_OFF"> Off
	                       // <GPIO_PULL_UP"> Pull-up
	                       // <GPIO_PULL_DOWN"> Pull-down
	                       GPIO_PULL_OFF);

	gpio_set_pin_function(PA08, PINMUX_PA08D_SERCOM2_PAD0);

	gpio_set_pin_pull_mode(PA09,
	                       // <y> Pull configuration
	                       // <id> pad_pull_config
	                       // <GPIO_PULL_OFF"> Off
	                       // <GPIO_PULL_UP"> Pull-up
	                       // <GPIO_PULL_DOWN"> Pull-down
	                       GPIO_PULL_OFF);

	gpio_set_pin_function(PA09, PINMUX_PA09D_SERCOM2_PAD1);
}

void I2C_0_CLOCK_init(void)
{
	hri_gclk_write_PCHCTRL_reg(GCLK, SERCOM2_GCLK_ID_CORE, CONF_GCLK_SERCOM2_CORE_SRC | (1 << GCLK_PCHCTRL_CHEN_Pos));
	hri_gclk_write_PCHCTRL_reg(GCLK, SERCOM2_GCLK_ID_SLOW, CONF_GCLK_SERCOM2_SLOW_SRC | (1 << GCLK_PCHCTRL_CHEN_Pos));

	hri_mclk_set_APBCMASK_SERCOM2_bit(MCLK);
}

void I2C_0_init(void)
{
	I2C_0_CLOCK_init();
	i2c_m_sync_init(&I2C_0, SERCOM2);
	I2C_0_PORT_init();
}

void EDBG_COM_1_PORT_init(void)
{

	gpio_set_pin_function(PA22, PINMUX_PA22C_SERCOM3_PAD0);

	gpio_set_pin_function(PA23, PINMUX_PA23C_SERCOM3_PAD1);
}

void EDBG_COM_1_CLOCK_init(void)
{
	hri_gclk_write_PCHCTRL_reg(GCLK, SERCOM3_GCLK_ID_CORE, CONF_GCLK_SERCOM3_CORE_SRC | (1 << GCLK_PCHCTRL_CHEN_Pos));
	hri_gclk_write_PCHCTRL_reg(GCLK, SERCOM3_GCLK_ID_SLOW, CONF_GCLK_SERCOM3_SLOW_SRC | (1 << GCLK_PCHCTRL_CHEN_Pos));

	hri_mclk_set_APBCMASK_SERCOM3_bit(MCLK);
}

void EDBG_COM_1_init(void)
{
	EDBG_COM_1_CLOCK_init();
	usart_sync_init(&EDBG_COM_1, SERCOM3, (void *)NULL);
	EDBG_COM_1_PORT_init();
}

void SPI_0_PORT_init(void)
{

	// Set pin direction to input
	gpio_set_pin_direction(PB16, GPIO_DIRECTION_IN);

	gpio_set_pin_pull_mode(PB16,
	                       // <y> Pull configuration
	                       // <id> pad_pull_config
	                       // <GPIO_PULL_OFF"> Off
	                       // <GPIO_PULL_UP"> Pull-up
	                       // <GPIO_PULL_DOWN"> Pull-down
	                       GPIO_PULL_OFF);

	gpio_set_pin_function(PB16, PINMUX_PB16C_SERCOM5_PAD0);

	gpio_set_pin_level(PB22,
	                   // <y> Initial level
	                   // <id> pad_initial_level
	                   // <false"> Low
	                   // <true"> High
	                   false);

	// Set pin direction to output
	gpio_set_pin_direction(PB22, GPIO_DIRECTION_OUT);

	gpio_set_pin_function(PB22, PINMUX_PB22D_SERCOM5_PAD2);

	gpio_set_pin_level(PB23,
	                   // <y> Initial level
	                   // <id> pad_initial_level
	                   // <false"> Low
	                   // <true"> High
	                   false);

	// Set pin direction to output
	gpio_set_pin_direction(PB23, GPIO_DIRECTION_OUT);

	gpio_set_pin_function(PB23, PINMUX_PB23D_SERCOM5_PAD3);
}

void SPI_0_CLOCK_init(void)
{
	hri_gclk_write_PCHCTRL_reg(GCLK, SERCOM5_GCLK_ID_CORE, CONF_GCLK_SERCOM5_CORE_SRC | (1 << GCLK_PCHCTRL_CHEN_Pos));
	hri_gclk_write_PCHCTRL_reg(GCLK, SERCOM5_GCLK_ID_SLOW, CONF_GCLK_SERCOM5_SLOW_SRC | (1 << GCLK_PCHCTRL_CHEN_Pos));

	hri_mclk_set_APBDMASK_SERCOM5_bit(MCLK);
}

void SPI_0_init(void)
{
	SPI_0_CLOCK_init();
	spi_m_sync_init(&SPI_0, SERCOM5);
	SPI_0_PORT_init();
}

void system_init(void)
{
	init_mcu();

	// GPIO on PB10

	gpio_set_pin_level(LED0,
	                   // <y> Initial level
	                   // <id> pad_initial_level
	                   // <false"> Low
	                   // <true"> High
	                   true);

	// Set pin direction to output
	gpio_set_pin_direction(LED0, GPIO_DIRECTION_OUT);

	gpio_set_pin_function(LED0, GPIO_PIN_FUNCTION_OFF);

	USART_0_init();

	I2C_0_init();

	EDBG_COM_1_init();

	SPI_0_init();
}

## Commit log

2019-05-05 Create prototype folder
    New folder for dev. board prototype
2019-05-06 Prototype Hardware Schematic
    [Xplained_RFM98W.sch]
2019-05-10 Sort out naming mistake RFM98W
    Hope I didn't break it all!
    [RFM98W.c, RFM98W.h, atmel_start_pins.h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]
2019-05-11 Added another GPS passthrough utility, using asyc UART
2019-05-13 Update Prototype schematic
    [Xplained_RFM98W.sch]
2019-05-15 Added the basic tracker project. It is in folder 'EDBG UART erert'
    It is in folder 'EDBG UART erert'. I used that directory name earlier but now I don't know how to change it to something more descriptive
2019-06-28 Fixed the bug with the checksum errors
    [main.h]
2019-07-23 Add Kicad file
    [ICSSPicoTracker2.kicad_pcb, ICSSPicoTracker2.sch, ICSSPicoTrackerGPS.sch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]
2019-07-24 Add Spice Files
    Add Spice directory and add files for radio telemetry filter simulations
2019-08-03 Add GPS, Remove FM
    [ICSSPicoTracker_MCU.sch]
2019-08-17 Updated Scehematics and Footprints
    [ICSSPicoTracker2.sch, ICSSPicoTrackerGPS.sch, ICSSPicoTrackerPower.sch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]
2019-08-18 Add Antenna footprints
    [ICSSPicoTracker2.kicad_pcb, ICSSPicoTrackerPower.sch, ICSSPicoTrackerRadio.sch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]
2019-08-21 Smaller Antenna and try some layouts
    [ICSSPicoTracker2.kicad_pcb, ICSSPicoTrackerGPS.sch, ICSSPicoTrackerRadio.sch]
2019-08-24 Some more ERC fixes
    [ICSSPicoTrackerGPS.sch, ICSSPicoTrackerPower.sch, ICSSPicoTracker_MCU.sch]
2019-09-05 fully wired up the LD3985 LDO
    [ICSSPicoTrackerGPS.sch, ICSSPicoTracker_MCU.sch]
2019-09-07 Revert "fully wired up the LD3985 LDO"
    This reverts commit 04a440f3a08b8c97db9d4cc44cd5207f890db50a.
    [ICSSPicoTrackerGPS.sch, ICSSPicoTracker_MCU.sch]

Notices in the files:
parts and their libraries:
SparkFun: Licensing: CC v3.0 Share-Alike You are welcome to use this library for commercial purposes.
